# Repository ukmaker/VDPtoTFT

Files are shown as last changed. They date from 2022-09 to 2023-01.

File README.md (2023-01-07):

# VDPtoTFT
Converts the output from an old TMS9928A Video Display Processor to drive a small TFT panel using either an SPI or a parallel interface. For lovers of microcomputers from the 70s and 80s.

# Introduction
Once upon a time, when I were a lad, I had my very own Z80 based computer (Nascom 2) which I had built from a kit and then extended with cards of my own design. I always wanted a colour graphics card, and was most envious of computers which used the Texas Instruments TMS9918 family of chips. I never did get a graphics card, though I did build a two-channel DtoA converter and used that to drive my oscilloscope.

So, wind forward to todayish and I'm in the middle of a project to build a drum machine, when I discover a simple computer I'd cobbled together on a breadboard and which was now living in a box in the shed. Putting two and two together, I decided to see whether it would have been possible to build the drum machine using 70s technology. First thing to do was to decide on what would take the place of the TFT display. You can see where this is going, and how very deep that rabbit-hole is.

Right.

So, for anyone with an old computer using one of the TMS9928/29/128/129 chips, here is a project which will allow you to use it to drive a small, cheap TFT display. It won't work with the TMS9918 chips because it needs to sample the Y and R-Y outputs which don't exist on the TMS9918.

All it needs is an STM32G4 microcontroller. I used a Nucleo-G474RE board because I had one already.

# But Does It Work?
Yes, it does. I confess to being suprised that I was able to make it work. There is a little bit of flicker in a couple of the colours, due to noise in the sampling process, so I have a couple of improvements I'll be working on. 
- Tweak the on-board VREF to output a lower voltage (2.8V instead of 3.25) thus potentially increasing the ADC accuracy.
- Build a better custom PCB. The first version has some errors.

I may end up making a custom PCB including the TMS chip so there's an all-in-one solution for RC2014 folks. Let me know if you would like this.

# Pictures

My VDP board with the Nucleo bolted to the side
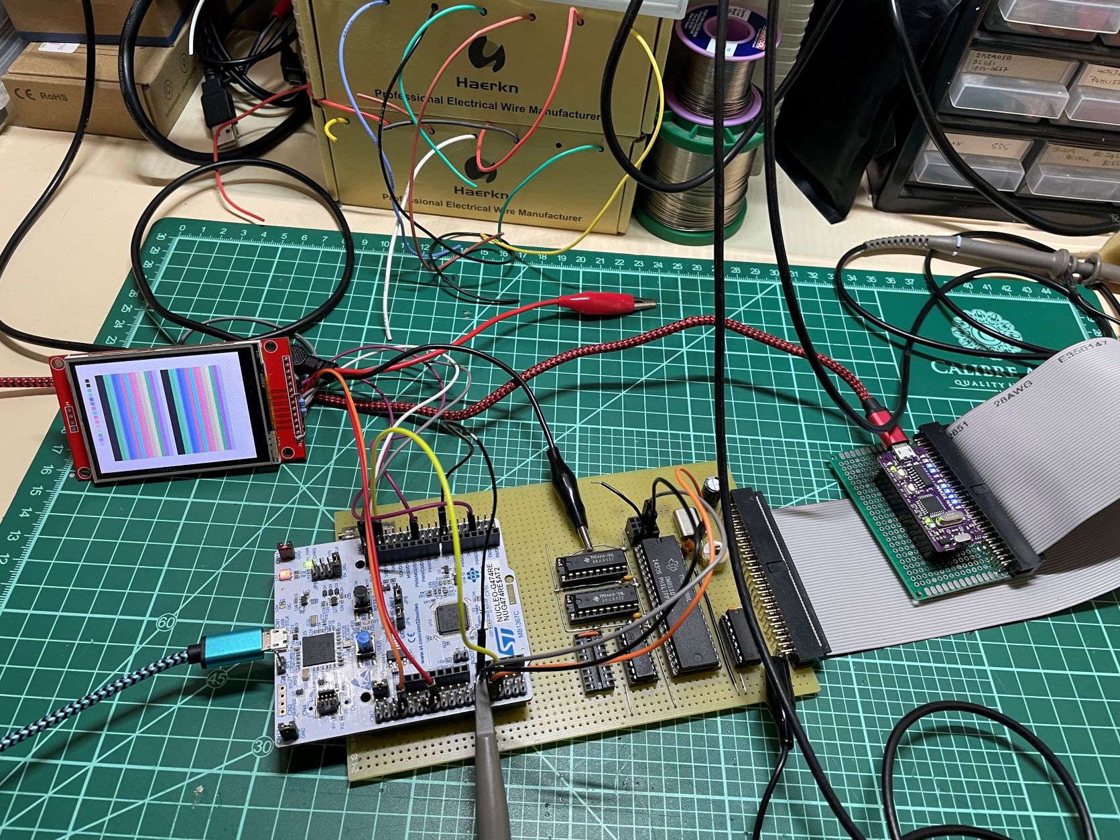
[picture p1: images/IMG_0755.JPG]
VDP Board


Yes, I'm cheating. Driving the VDP from an Arduino for now
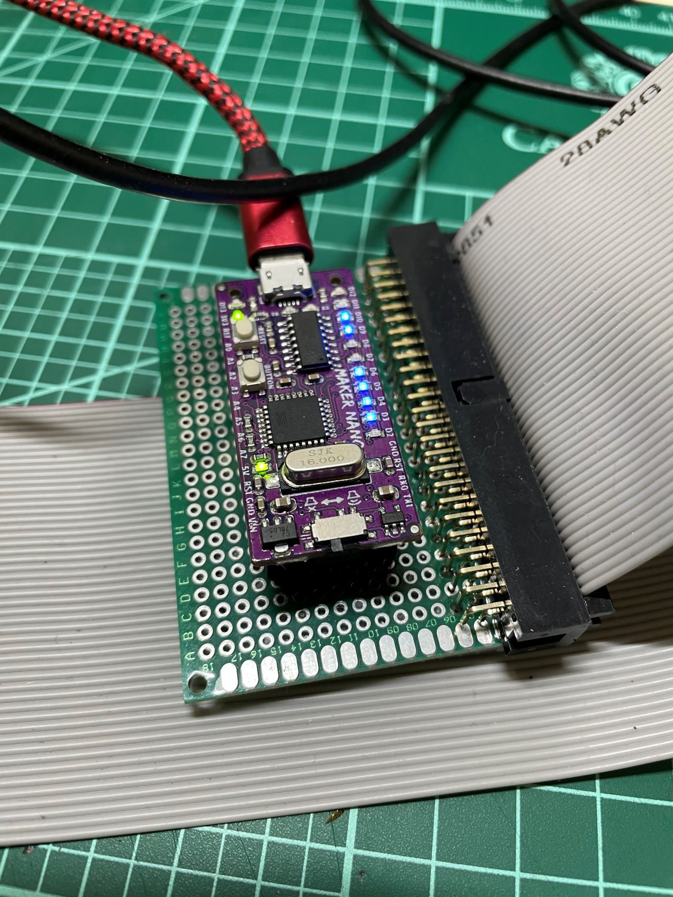
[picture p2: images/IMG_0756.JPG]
Arduino Driving VDP


Close up of an image on the SPI display
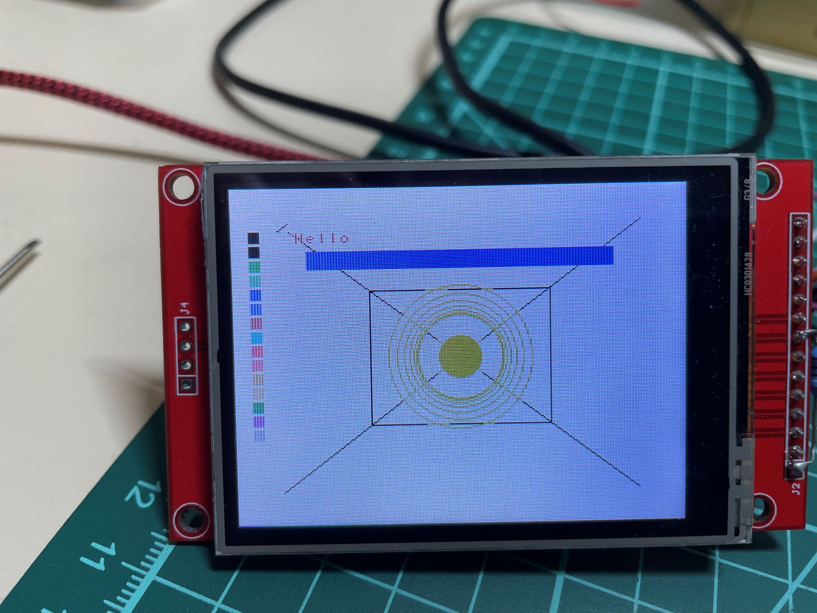
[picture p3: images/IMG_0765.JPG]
SPI Display


And a test-pattern on the parallel display
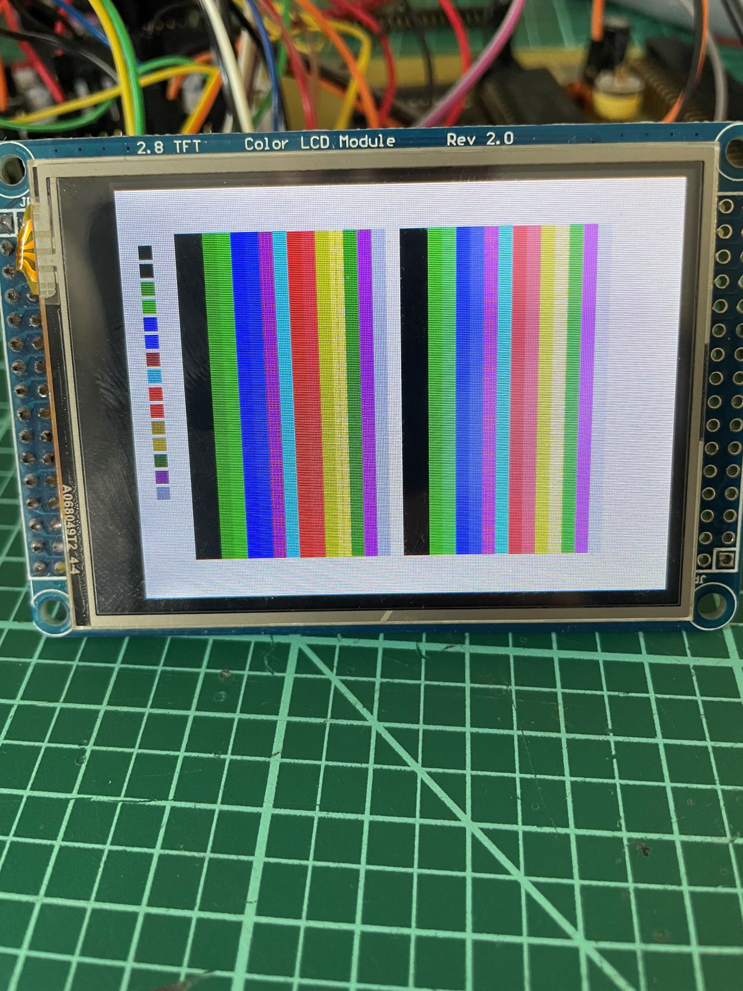
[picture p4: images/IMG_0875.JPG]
Parallel Display


Here's a bit of test-gear I built to help. 
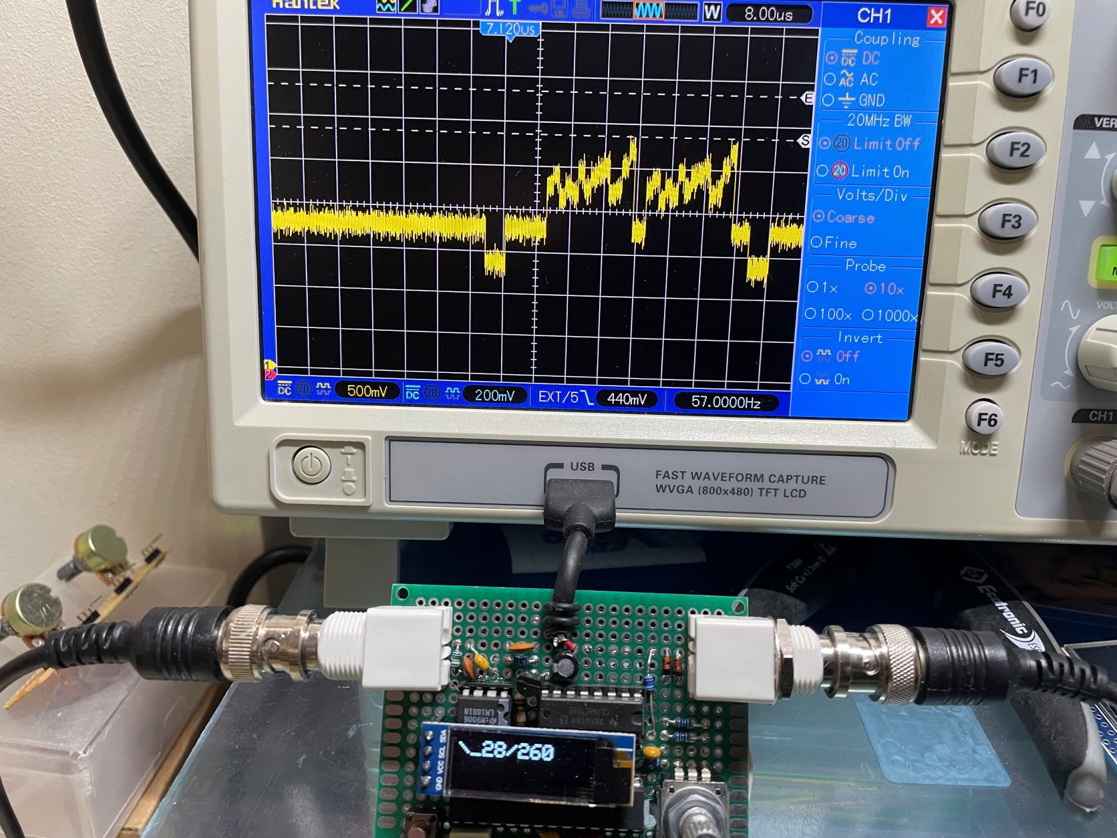
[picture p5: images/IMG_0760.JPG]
VideoTrigger
 - see my other project [VideoTrigger](https://github.com/ukmaker/VideoTrigger) for details

# Theory Of Operation

The following block diagram shows the essentials of how this works.

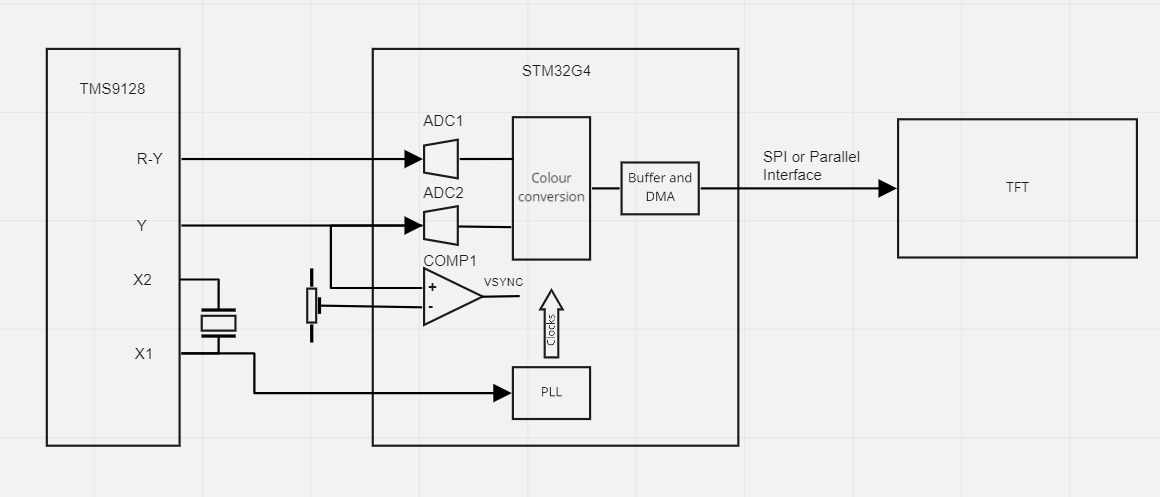
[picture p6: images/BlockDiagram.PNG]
Block Diagram


The output of the VDP's crystal oscillator is used to drive the clock input on the STM32G4. The STM32G4's PLL multiplies the VDP's 10.7MHz clock up by a factor of 16 to 171.2 MHz (thus ever so slightly overclocking the STM32, which is rated to 170MHz). This ensures that all processing happens synchronously to the signals being generated by the VDP. 

The VDP is capable of producing 16 different colours, and the generated signal comes from three outputs - Y, R-Y and B-Y. It turns out that sampling only Y and R-Y give us enough information to deduce the colour being generated, which is good as it reduces the amount of processing needed. These signals are fed to the STM's ADC1 and ADC2 which are operated in "dual-mode". This means that both inputs are sampled synchronously under the control of ADC1. The samples are place in a small circular buffer using DMA.

The ADCs are triggered by a timer which is in turn triggered by a comparator which samples the Y signal to determine when horizontal and vertical sync events happen (when the Y signal level drops below the black value). A trimpot is used to set this level correctly. Once a sync event is detected a chain of two timers is used to generate the sampling signals for the ADCs. The first timer (TIM4) starts the second timer (TIM1) after a delay calculated such that TIM1's first output pulse will happen just as the first pixel data is output by the VDP. This delay is approx 12 microseconds from the horizontal sync pulse.

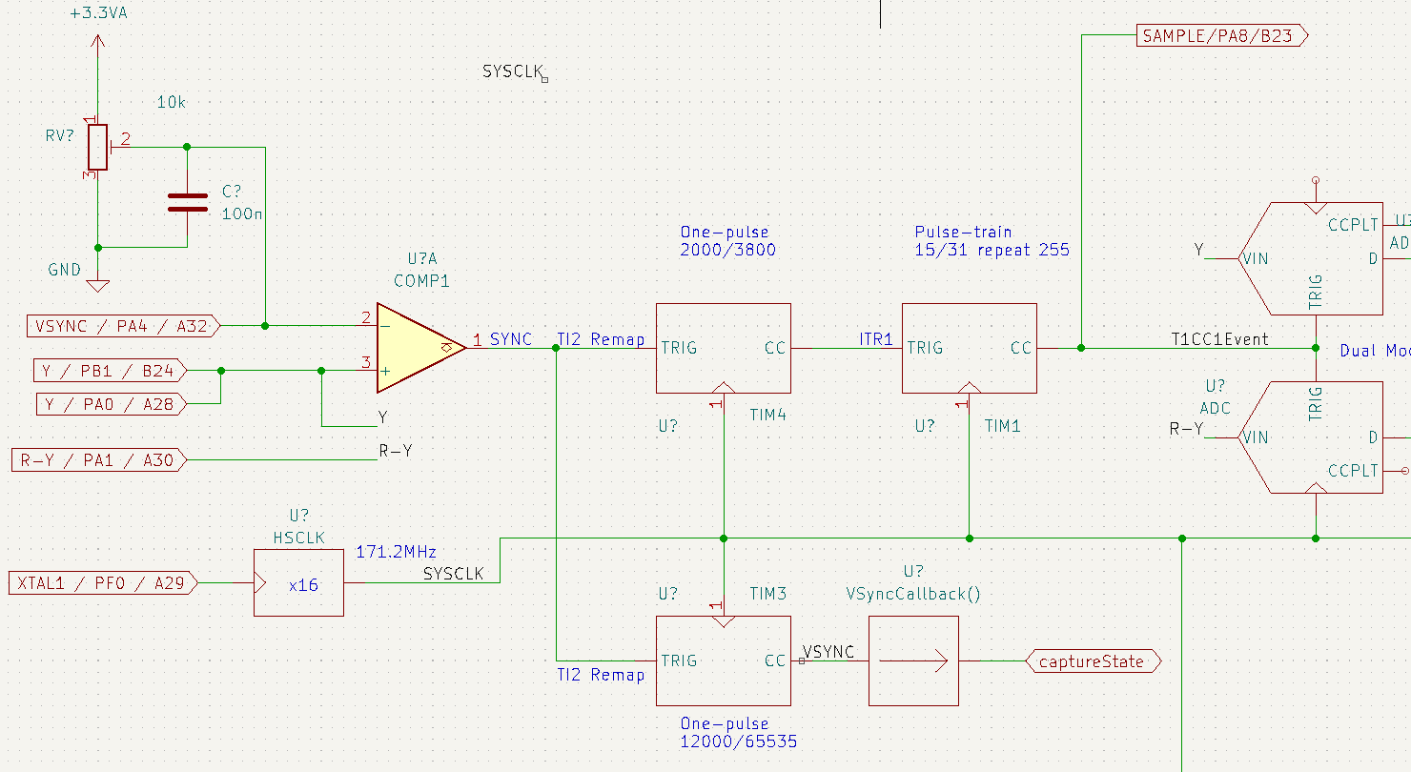
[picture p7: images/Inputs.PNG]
ADC Configuration

The ADC's DMA channel is set to run in circular mode, with a buffer size of 512 half-words. The DMA unit will raise a transfer-half-complete interrupt after 256 transfers, which corresponds to one complete line of pixels. There are now approx 16us available for processing before the start of the next line. The interrupt service routine (ADCCallback()) uses this time to read the data from the buffer, map it from read values (samples are 6 bits per channel) to 16-bit RGB values and store them in the dma buffer, which holds an entire frame of samples. This repeats on the transfer-complete interrupt and so on until and entire frame has been sampled and mapped. 

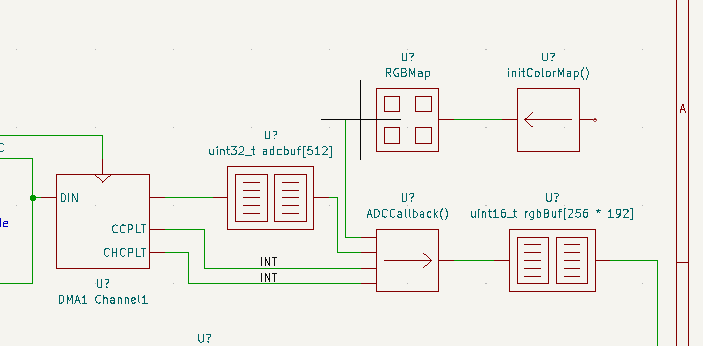
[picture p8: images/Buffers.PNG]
Buffers

If the sync signal stays low for more than one line-time (64 us), TIM3 will detect this as a vertical sync, and raise an interrupt. This is used by the state-machine running in the main() loop to initiate the DMA transfer from the RGB buffer to either the SPI unit or GPIO Port C if a parallel TFT is being used.

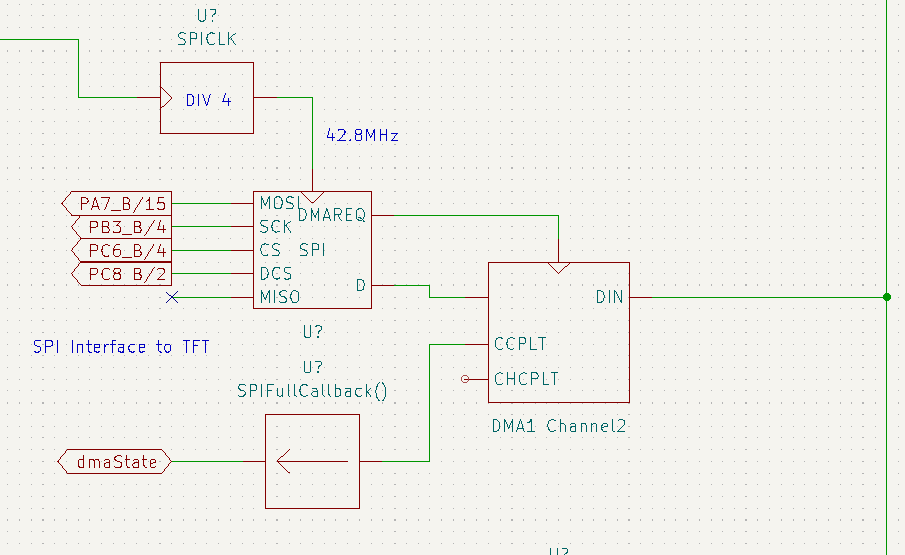
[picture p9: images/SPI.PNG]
SPI

If SPI is being used, the transfer happens in 4 blocks because the maximum size for a single DMA transfer is 65536 transfers. One full frame holds 256 pixels * 192 lines * 2 bytes of data = 98,304 transfers (SPI config for my screen is in bytes). I.e. too many transfers for a single DMA session. The SPI interface is clocked at 42.8MHz, even though the datasheet for the chip used in my display (ILI9341) says the maximum SPI clock speed is 10MHz! Even so, there just is not enough time in one frame to sample and transfer all the data so instead the state machine runs a sample for a frame and then takes a frame to refresh the screen. This is visible as 30Hz flicker on the screen. I have ordered a TMS9129 to use in place of the TMS9128. The TMS9129 is the European version which has a 50Hz refresh rate rather than the 60Hz of the TMS9128. With this lower frame rate I think I'll be able to refresh the screen over SPI at a full 50Hz, thus eliminating the flicker.

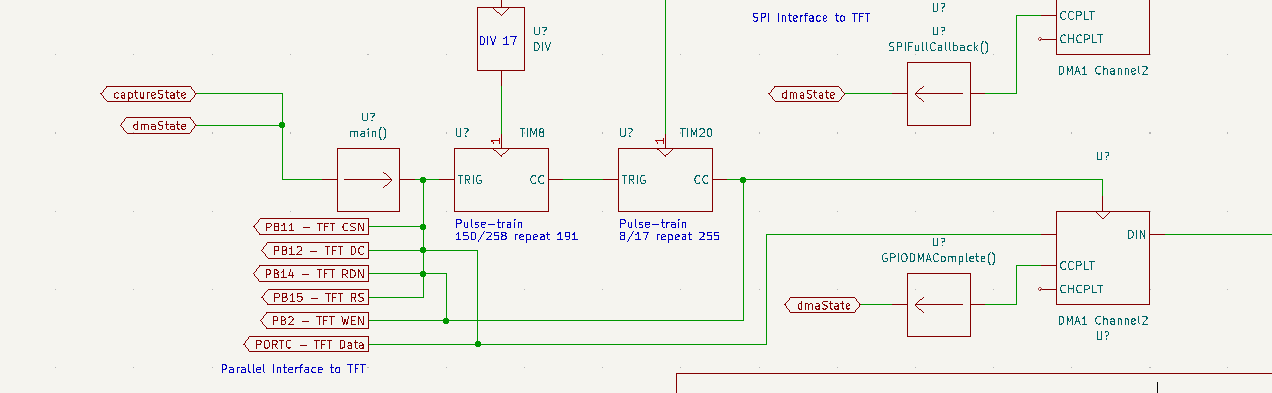
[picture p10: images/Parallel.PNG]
Parallel

If a parallel interface is being used the DMA controller can transfer the entire 49K RGB buffer in one go at 60Hz, so there is no flicker. The parallel interface runs at 10MHz.

# Building
This is a project built using the STM32CubeIDE and the STM32 HAL. If this offends you, feel free to fork my repo and rewrite it in whatever manner you choose.

For now, there is little to do to build this other than

- Install STM32CubeIDE if you haven't already got it
- Download this repo
- Open the project in the IDE and build it
- Tweak appropriate jumpers on your Nucleo (see below)
- Wire up a trimpot to set the sync level
- Connect the Nucleo to the display of your choice (see below)
- Connect the Nucleo to your VDP
- Plug everything in 
- Click Run in the IDE

Note that all the code etc is in the V1.0 directory. I had some small learning opportunities once I'd received my first set of PCBs, and the changes in the V2.0 folder are just for the schematic and layout.

The ConverterBoard directory contains a schematic for implementing this directly with an STM32G474.

The VDPtoSPI directory contains pseudo-schematics for how the blocks in the MCU are used.

## Nucleo Tweaking
Because I needed to use quite a few pins in non-standard ways (for a Nucleo), I needed to remove quite a few jumpers. I'm not sure I remember them all now, but here goes:

### Using the clock from the VDP to drive HSE on PF0.
```
SB28 ON (Connect OSCIN to PF0 header pin)
SB24, SB25, SB26, 27 OFF 
```
### Connect PC14 and PC15 to header pins
```
SB29, SB32 ON
```

### The Sync Trimpot
The sync signal is derived by configuring Comparator 1 and feeding the positive input with the Y signal and the negative input with a constant voltage from a trimpot to set the threshold. Connecct a trimmer of e.g. 10K to 3V3 and GND, with the wiper going to PB1. You should also add a decoupling capacitor of e.g. 100n from PB1 to ground.

Once the board is up and running and you are feeding it a signal from your VDP, adjust the trimpot to obtain a stable display. This can bbe made easier with a two-channel scope attached to Y and PB1 so you can position the voltage on PB1 in the middle of the sync tips.

If you have trouble getting your scope to sync to the VDP signal you might want to look at my other project which is a tool to get a clean trigger off any chosen line on the display. https://github.com/ukmaker/VideoTrigger

## Connecting Your Display
The code is capable of driving displays using either an SPI or parallel interface. 

Configuration is in the file

`V1.0/STM32CubeIDE/VDPDMA/Core/Inc/configuration.h`

By default the code expects to use an SPI interface using SPI2
```
  CS - PB9
  DC - PB8
  RS - PD2
  MOSI - PA11
  SCK - PF1
```
If you uncomment the line
`#define PAR_TFT`
then the code will expect a parallel display
```
D0 - D15 -> PC0 - PC15
CS - PB11
RS - PB12
RD - PB14
RESET - PB15
```

# Making the PCB
Don't use the V1.0 board - there are some annoying errors.

Also, I hope you're better at soldering surface-mount than I am. My first attempt is best described using words like "embarrassment", "cringe" and "pillock". Watch out for those STM chips. Sometimes they have two little circles on the package. Make sure you know which one means Pin 1 Is Here. Then make sure again.

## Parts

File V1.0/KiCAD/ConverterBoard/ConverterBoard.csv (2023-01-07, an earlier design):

Source: | Z:\duncan\EDA\VDPtoTFT\V1.0\KiCAD\ConverterBoard\ConverterBoard.kicad_sch
Date: | 05/11/2022 14:20:18
Tool: | Eeschema (6.0.6)
Generator: | C:\Program Files\KiCad\6.0\bin\scripting\plugins/bom_csv_grouped_by_value_with_fp.py
Component Count: | 48
Ref | Qnty | Value | Cmp name | Footprint | Description | Vendor
C1, C4, C5, C6, C7, C8, C9, C11, C12, C13, C14, C16, C17, | 13 | 100n | C | Capacitor_SMD:C_0805_2012Metric | Unpolarized capacitor
C2, C3, | 2 | 22p | C | Capacitor_SMD:C_0805_2012Metric | Unpolarized capacitor
C10, | 1 | 1u | C | Capacitor_SMD:C_0805_2012Metric | Unpolarized capacitor
C15, C18, C19, | 3 | 4u7 | C | Capacitor_SMD:C_0805_2012Metric | Unpolarized capacitor
D1, | 1 | ESDA6V1-5SC6 | ESDA6V1-5SC6 | Package_TO_SOT_SMD:SOT-23-6 | Quintuple bidirectional transil, Suppressor for ESD protection, 6V1 Breakdown, SOT-23-6
ENCODER1, | 1 | ENCODER | Conn_01x05 | Connector_PinHeader_2.54mm:PinHeader_1x05_P2.54mm_Vertical | Generic connector, single row, 01x05, script generated (kicad-library-utils/schlib/autogen/connector/)
J1, | 1 | 5V Power | Conn_01x02 | TerminalBlock:TerminalBlock_bornier-2_P5.08mm | Generic connector, single row, 01x02, script generated (kicad-library-utils/schlib/autogen/connector/)
J2, J3, J5, | 3 | Conn_01x02 | Conn_01x02 | Connector_PinHeader_2.54mm:PinHeader_1x02_P2.54mm_Vertical | Generic connector, single row, 01x02, script generated (kicad-library-utils/schlib/autogen/connector/)
J6, | 1 | TFT Parallel Port | Conn_02x16_Odd_Even | Connector_PinHeader_2.54mm:PinHeader_2x16_P2.54mm_Vertical | Generic connector, double row, 02x16, odd/even pin numbering scheme (row 1 odd numbers, row 2 even numbers), script generated (kicad-library-utils/schlib/autogen/connector/)
J7, | 1 | GPIO | Conn_02x04_Odd_Even | Connector_PinHeader_2.54mm:PinHeader_2x04_P2.54mm_Vertical | Generic connector, double row, 02x04, odd/even pin numbering scheme (row 1 odd numbers, row 2 even numbers), script generated (kicad-library-utils/schlib/autogen/connector/)
J8, | 1 | TFT SPI Port | Conn_02x04_Odd_Even | Connector_PinHeader_2.54mm:PinHeader_2x04_P2.54mm_Vertical | Generic connector, double row, 02x04, odd/even pin numbering scheme (row 1 odd numbers, row 2 even numbers), script generated (kicad-library-utils/schlib/autogen/connector/)
L1, | 1 | 600R @ 100MHz | L | Inductor_SMD:L_0805_2012Metric_Pad1.15x1.40mm_HandSolder | Inductor
R1, R2, R3, R4, R6, | 5 | 47R | R | Resistor_SMD:R_0805_2012Metric_Pad1.20x1.40mm_HandSolder | Resistor
R5, | 1 | 10R | R | Resistor_SMD:R_0805_2012Metric_Pad1.20x1.40mm_HandSolder | Resistor
R7, | 1 | 3K9 | R | Resistor_SMD:R_0805_2012Metric_Pad1.20x1.40mm_HandSolder | Resistor
RV1, | 1 | 10K | R_Potentiometer_Trim | Potentiometer_THT:Potentiometer_Bourns_3005_Horizontal | Trim-potentiometer
ST-LINK1, | 1 | ST-LINK | Conn_02x05_Odd_Even | Connector_PinHeader_2.54mm:PinHeader_2x05_P2.54mm_Vertical | Generic connector, double row, 02x05, odd/even pin numbering scheme (row 1 odd numbers, row 2 even numbers), script generated (kicad-library-utils/schlib/autogen/connector/)
TP1, TP2, TP3, TP4, TP5, TP6, TP7, | 7 | TestPoint | TestPoint | TestPoint:TestPoint_THTPad_1.5x1.5mm_Drill0.7mm | test point
U1, U2, | 2 | XC6503D331PR-G | XC6503D331PR-G | Package_TO_SOT_SMD:SOT-89-5_Handsoldering
U3, | 1 | MCU_STM32G474RCT6 | MCU_STM32G474RE | Package_QFP:LQFP-64_10x10mm_P0.5mm

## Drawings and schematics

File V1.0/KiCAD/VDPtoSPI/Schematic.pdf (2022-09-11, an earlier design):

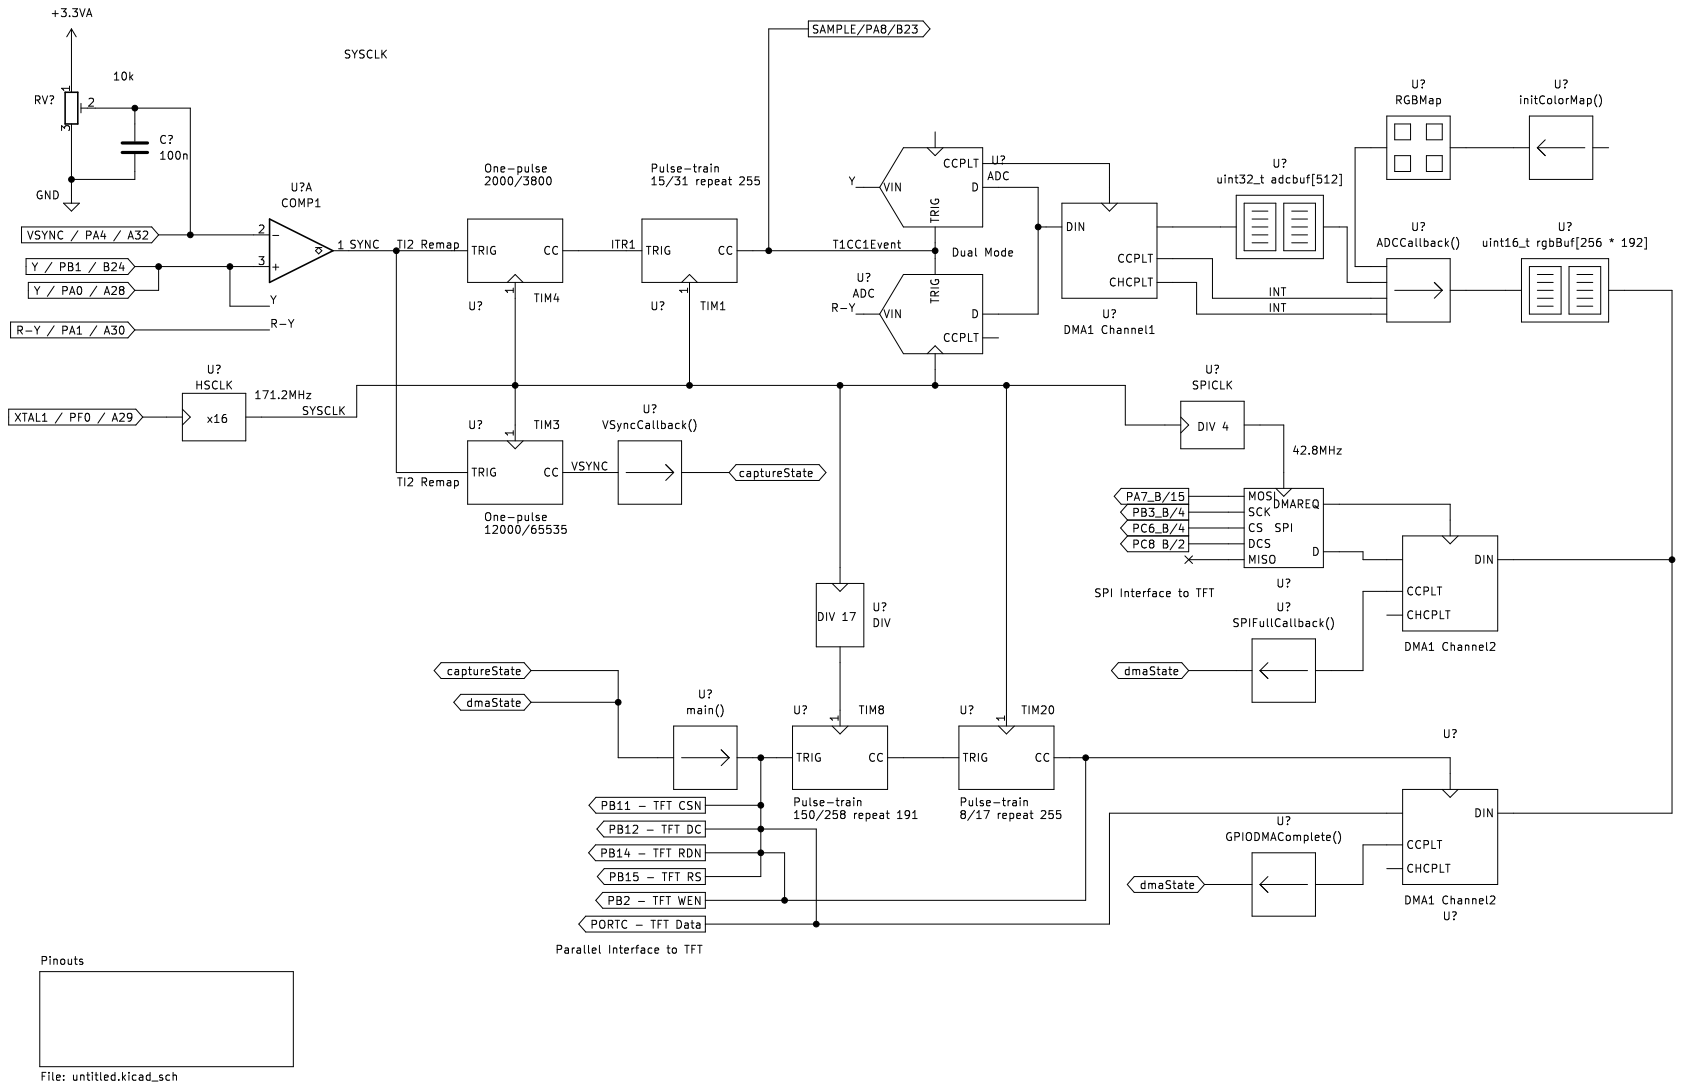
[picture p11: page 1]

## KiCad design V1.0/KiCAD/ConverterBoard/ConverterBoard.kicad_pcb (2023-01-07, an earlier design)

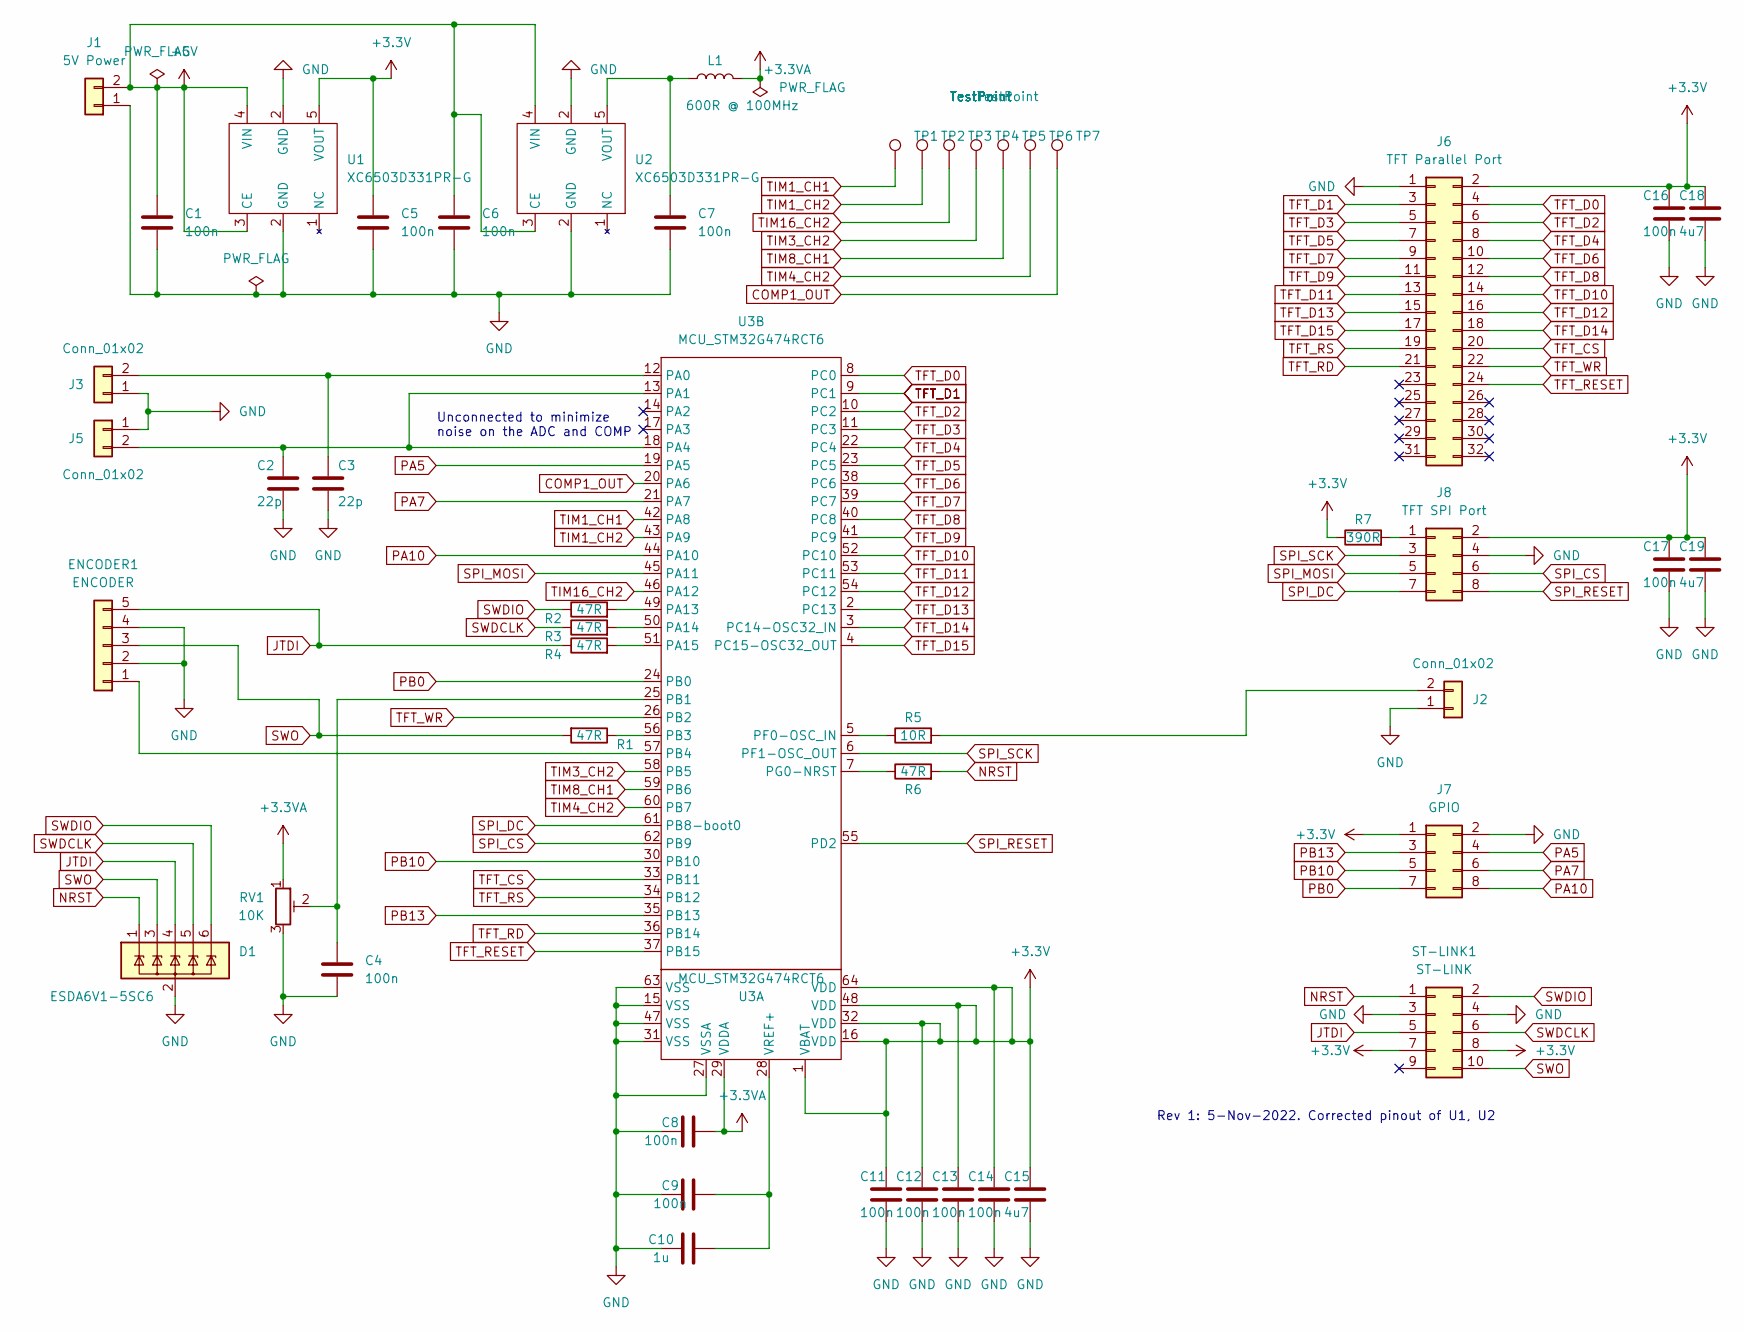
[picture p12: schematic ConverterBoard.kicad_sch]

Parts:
C1, C4, C5, C6, C7, C8, C9, C11, C12, C13, C14, C16, C17: 100n; C_0805_2012Metric
C2, C3: 22p; C_0805_2012Metric
C10: 1u; C_0805_2012Metric
C15, C18, C19: 4u7; C_0805_2012Metric
D1: ESDA6V1-5SC6; SOT-23-6
ENCODER1: ENCODER; PinHeader_1x05_P2.54mm_Vertical
J1: 5V Power; TerminalBlock_bornier-2_P5.08mm
J2, J3, J5: Conn_01x02; PinHeader_1x02_P2.54mm_Vertical
J6: TFT Parallel Port; PinHeader_2x16_P2.54mm_Vertical
J7: GPIO; PinHeader_2x04_P2.54mm_Vertical
J8: TFT SPI Port; PinHeader_2x04_P2.54mm_Vertical
L1: 600R @ 100MHz; L_0805_2012Metric_Pad1.15x1.40mm_HandSolder
R1, R2, R3, R4, R6: 47R; R_0805_2012Metric_Pad1.20x1.40mm_HandSolder
R5: 10R; R_0805_2012Metric_Pad1.20x1.40mm_HandSolder
R7: 390R; R_0805_2012Metric_Pad1.20x1.40mm_HandSolder
RV1: 10K; Potentiometer_Bourns_3005_Horizontal
ST-LINK1: ST-LINK; PinHeader_2x05_P2.54mm_Vertical
TP1, TP2, TP3, TP4, TP5, TP6, TP7: TestPoint; TestPoint_THTPad_1.5x1.5mm_Drill0.7mm
U1, U2: XC6503D331PR-G; SOT-89-5_Handsoldering
U3: MCU_STM32G474RCT6; LQFP-64_10x10mm_P0.5mm

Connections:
+3.3V: C5.1, C11.1, C12.1, C13.1, C14.1, C15.1, C16.1, C17.1, C18.1, C19.1, J6.2, J7.1, J8.2, R7.1, ST-LINK1.7, ST-LINK1.8, U1.5 (VOUT), U3.1 (VBAT), U3.16 (VDD), U3.32 (VDD), U3.48 (VDD), U3.64 (VDD)
+3.3VA: C8.2, L1.2, RV1.1, U3.29 (VDDA)
+5V: C1.1, C6.1, J1.2, U1.3 (CE), U1.4 (VIN), U2.3 (CE), U2.4 (VIN)
COMP1_OUT: TP7.1, U3.20 (PA6)
GND: C1.2, C2.2, C3.2, C4.2, C5.2, C6.2, C7.2, C8.1, C9.1, C10.1, C11.2, C12.2, C13.2, C14.2, C15.2, C16.2, C17.2, C18.2, C19.2, D1.2 (GND), ENCODER1.2, ENCODER1.4, J1.1, J2.1, J3.1, J5.1, J6.1, J7.2, J8.4, RV1.3, ST-LINK1.3, ST-LINK1.4, U1.2 (GND), U2.2 (GND), U3.15 (VSS), U3.27 (VSSA), U3.31 (VSS), U3.47 (VSS), U3.63 (VSS)
JTDI: D1.4 (IO3), ENCODER1.5, R4.1, ST-LINK1.5
NRST: D1.1 (IO1), R6.2, ST-LINK1.1
unnamed: C2.1, J5.2, U3.13 (PA1), U3.18 (PA4)
unnamed: C3.1, J3.2, U3.12 (PA0)
unnamed: C4.1, RV1.2, U3.25 (PB1)
unnamed: C9.2, C10.2, U3.28 (VREF+)
unnamed: ENCODER1.1, U3.57 (PB4)
unnamed: J2.2, R5.2
unnamed: J8.1, R7.2
unnamed: R1.1, U3.56 (PB3)
unnamed: R2.2, U3.49 (PA13)
unnamed: R3.2, U3.50 (PA14)
unnamed: R4.2, U3.51 (PA15)
unnamed: R5.1, U3.5 (PF0-OSC_IN)
unnamed: R6.1, U3.7 (PG0-NRST)
unnamed: C7.1, L1.1, U2.5 (VOUT)
PA5: J7.4, U3.19 (PA5)
PA7: J7.6, U3.21 (PA7)
PA10: J7.8, U3.44 (PA10)
PB0: J7.7, U3.24 (PB0)
PB10: J7.5, U3.30 (PB10)
PB13: J7.3, U3.35 (PB13)
SPI_CS: J8.6, U3.62 (PB9)
SPI_DC: J8.7, U3.61 (PB8-boot0)
SPI_MOSI: J8.5, U3.45 (PA11)
SPI_RESET: J8.8, U3.55 (PD2)
SPI_SCK: J8.3, U3.6 (PF1-OSC_OUT)
SWDCLK: D1.5 (IO4), R3.1, ST-LINK1.6
SWDIO: D1.6 (IO5), R2.1, ST-LINK1.2
SWO: D1.3 (IO2), ENCODER1.3, R1.2, ST-LINK1.10
TFT_CS: J6.20, U3.33 (PB11)
TFT_D0: J6.4, U3.8 (PC0)
TFT_D1: J6.3, U3.9 (PC1)
TFT_D2: J6.6, U3.10 (PC2)
TFT_D3: J6.5, U3.11 (PC3)
TFT_D4: J6.8, U3.22 (PC4)
TFT_D5: J6.7, U3.23 (PC5)
TFT_D6: J6.10, U3.38 (PC6)
TFT_D7: J6.9, U3.39 (PC7)
TFT_D8: J6.12, U3.40 (PC8)
TFT_D9: J6.11, U3.41 (PC9)
TFT_D10: J6.14, U3.52 (PC10)
TFT_D11: J6.13, U3.53 (PC11)
TFT_D12: J6.16, U3.54 (PC12)
TFT_D13: J6.15, U3.2 (PC13)
TFT_D14: J6.18, U3.3 (PC14-OSC32_IN)
TFT_D15: J6.17, U3.4 (PC15-OSC32_OUT)
TFT_RD: J6.21, U3.36 (PB14)
TFT_RESET: J6.24, U3.37 (PB15)
TFT_RS: J6.19, U3.34 (PB12)
TFT_WR: J6.22, U3.26 (PB2)
TIM1_CH1: TP1.1, U3.42 (PA8)
TIM1_CH2: TP2.1, U3.43 (PA9)
TIM3_CH2: TP4.1, U3.58 (PB5)
TIM4_CH2: TP6.1, U3.60 (PB7)
TIM8_CH1: TP5.1, U3.59 (PB6)
TIM16_CH2: TP3.1, U3.46 (PA12)

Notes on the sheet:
Rev 1: 5-Nov-2022. Corrected pinout of U1, U2
Unconnected to minimize noise on the ADC and COMP

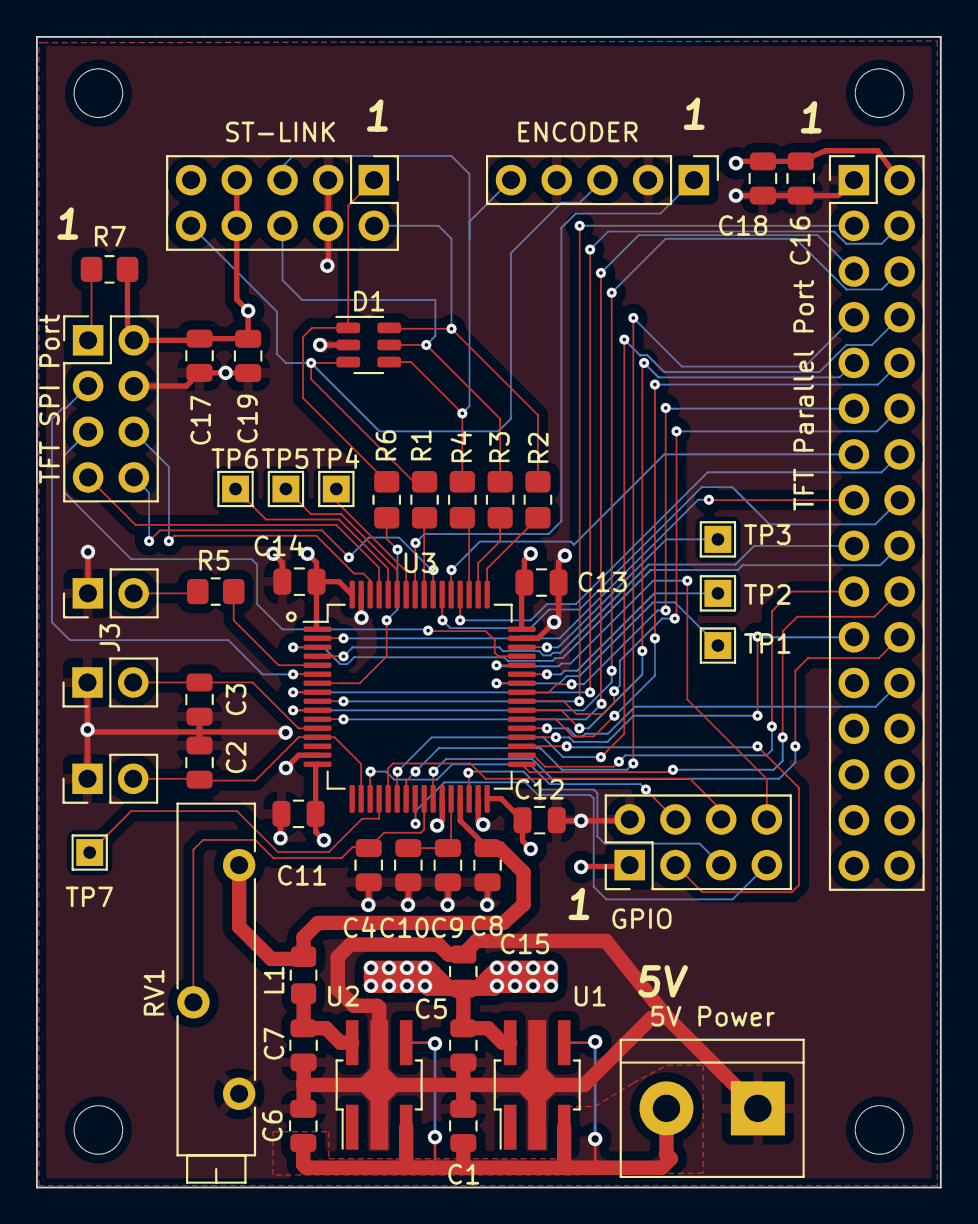
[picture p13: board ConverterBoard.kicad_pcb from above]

Board: 4 copper layers, 50.2 x 63.9 mm, 48 parts (0 on the bottom side), 62 nets.

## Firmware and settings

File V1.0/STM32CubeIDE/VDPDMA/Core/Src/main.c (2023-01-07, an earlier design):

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
/* Includes ------------------------------------------------------------------*/
#include "main.h"
#include "adc.h"
#include "comp.h"
#include "dma.h"
#include "spi.h"
#include "tim.h"
#include "gpio.h"

/* USER CODE BEGIN Includes */
#include "vdp.h"
#include "math.h"
/* USER CODE END Includes */

/* USER CODE BEGIN PD */

#define BLANKING_LINES (28 + (260 - 249))
#define FRAME_LINES 261

#define FIRST_VISIBLE_LINE 40
#define VISIBLE_LINES 192
#define LAST_VISIBLE_LINE (FIRST_VISIBLE_LINE + VISIBLE_LINES - 1)
#define BOTTOM_BORDER 32

#define PIXELS_PER_LINE 256

#define RGB_BUF_LEN (VISIBLE_LINES * PIXELS_PER_LINE)
#ifdef PAR_TFT
	#define RGB_BUF_CHUNKS 1
#else
	#define RGB_BUF_CHUNKS 4
#endif

#define RGB_BUF_CHUNK_BYTES (RGB_BUF_LEN / RGB_BUF_CHUNKS * 2)

#define CAPTURE_STATE_SEEKING_SYNC 0
#define CAPTURE_STATE_FOUND_SYNC 1
#define CAPTURE_STATE_START_GRAB 2
#define CAPTURE_STATE_GRABBING 3
#define CAPTURE_STATE_GRABBED 4
#define CAPTURE_STATE_IDLE 5

#define DMA_CAPTURE_STATE_IDLE 0
#define DMA_STATE_START 1
#define DMA_STATE_RUNNING 2
#define DMA_STATE_CHUNK_COMPLETE 3

#define SETUP_STATE_IDLE 0
#define SETUP_STATE_INIT 1
#define SETUP_STATE_SELECT_COLOUR 2
#define SETUP_STATE_INIT_Y 3
#define SETUP_STATE_TUNE_Y 4
#define SETUP_STATE_INIT_RY 5
#define SETUP_STATE_TUNE_RY 6
#define SETUP_STATE_TUNE_SAMPLE_TIME 7
#define SETUP_STATE_CANCEL 8

#define BUTTONEVENT_CLICK 1
#define BUTTON_EVENT_LONG_PRESS 2

/* USER CODE END PD */


void SystemClock_Config(void);
/* USER CODE BEGIN PFP */
extern void mysetup();
extern int mymain(uint16_t);
extern void pushpixel(uint16_t);

/* USER CODE END PFP */

/* USER CODE BEGIN 0 */

volatile uint16_t rgbBuf[RGB_BUF_LEN];
volatile uint32_t rgbBufIdx;
uint8_t rgbBufchunk;

volatile uint32_t adcbuf[512];
volatile uint32_t adc3buf[512];
volatile int16_t line;
volatile uint8_t captureState;
volatile uint8_t frameReady;
volatile uint8_t dmaState;

volatile uint16_t pix;

uint8_t encoderChanged;
uint8_t encoderPosition;
uint8_t lastPressed;
uint32_t encoderButtonChangedTicks;
uint8_t setupColour;

uint8_t raisedClickedEvent;
uint8_t raisedLongPressEvent;

uint8_t encoderClickedEvent;
uint8_t encoderLongPressEvent;


uint8_t setupState;

int _write(int file, char *ptr, int len) {
	int DataIdx;
	for (DataIdx = 0; DataIdx < len; DataIdx++) {
		ITM_SendChar(*ptr++);
	}
	return len;
}

/* USER CODE END 0 */

/**
  * @brief  The application entry point.
  * @retval int
  */
int main(void)
{
  /* MCU Configuration--------------------------------------------------------*/

  /* Reset of all peripherals, Initializes the Flash interface and the Systick. */
  HAL_Init();

  /* Configure the system clock */
  SystemClock_Config();

  /* Initialize all configured peripherals */
  MX_GPIO_Init();
  MX_DMA_Init();
  MX_TIM8_Init();
  MX_TIM1_Init();
  MX_ADC1_Init();
  MX_ADC2_Init();
  MX_TIM3_Init();
  MX_TIM2_Init();
  MX_TIM4_Init();
  MX_COMP1_Init();
  MX_TIM5_Init();
  MX_TIM16_Init();
  MX_TIM20_Init();
  MX_SPI2_Init();
  /* USER CODE BEGIN 2 */
	GPIOB->MODER = (GPIOB->MODER & 0xFFFFFFCF) | 0x00000010;
	mysetup();

	initBitMap();
	initColorMaps(0.43/0.47, 1.71);

#ifndef PAR_TFT
	swapRGBBytes();
#endif

	HAL_TIM_RegisterCallback(&htim3, HAL_TIM_OC_DELAY_ELAPSED_CB_ID,
			VSyncCallback);

	HAL_SPI_RegisterCallback(&hspi2, HAL_SPI_TX_COMPLETE_CB_ID,
			SPIFullCallback);
	HAL_DMA_RegisterCallback(&hdma_tim20_ch1, HAL_DMA_XFER_CPLT_CB_ID,
			GPIODMAComplete);

	HAL_ADC_RegisterCallback(&hadc1, HAL_ADC_CONVERSION_COMPLETE_CB_ID,
			ADCCallback);
	HAL_ADC_RegisterCallback(&hadc1, HAL_ADC_CONVERSION_HALF_CB_ID,
			ADCCallback);

	HAL_COMP_Start(&hcomp1);
	HAL_TIM_Base_Start(&htim4); // hysnc
	HAL_TIM_Base_Start(&htim1); // sample clock
	HAL_TIM_Base_Start_IT(&htim3); // vsync

	HAL_TIM_Base_Start(&htim8); // Parallel TFT DMA line clock
	HAL_TIM_Base_Start(&htim20); // Parallel TFT DMA pixel clock

	HAL_TIM_Base_Start(&htim2);

	__HAL_TIM_ENABLE_DMA(&htim20, TIM_DMA_CC1);

	if (HAL_TIM_OnePulse_Start(&htim4, TIM_CHANNEL_1) != HAL_OK) {
		/* Starting Error */
		Error_Handler();
	}
	if (HAL_TIM_OnePulse_Start(&htim1, TIM_CHANNEL_1) != HAL_OK) {
		/* Starting Error */
		Error_Handler();
	}
	if (HAL_TIM_OnePulse_Start_IT(&htim3, TIM_CHANNEL_1) != HAL_OK) {
		/* Starting Error */
		Error_Handler();
	}

	if (HAL_TIM_OnePulse_Start_IT(&htim20, TIM_CHANNEL_1) != HAL_OK) {
		/* Starting Error */
		Error_Handler();
	}
	HAL_TIM_OnePulse_Start(&htim8, TIM_CHANNEL_1);

	HAL_TIM_Encoder_Start(&htim2, TIM_CHANNEL_ALL);

	HAL_ADCEx_MultiModeStart_DMA(&hadc1, adcbuf, 512);

	line = BLANKING_LINES; // Line 0 is when we detect vsync at the end of a frame
	captureState = CAPTURE_STATE_SEEKING_SYNC;
	dmaState = DMA_CAPTURE_STATE_IDLE;
	setupState = SETUP_STATE_IDLE;
	encoderPosition = 0;
	encoderChanged = 0;
	lastPressed = GPIO_PIN_SET;
	encoderButtonChangedTicks = 0;
	encoderClickedEvent = 0;
	encoderLongPressEvent = 0;
	setupColour = 0;

	// set to true otherwise there will be a spurious event raised at startup
	raisedClickedEvent = 1;
	raisedLongPressEvent = 0;

	rgbBufIdx = 0;
	rgbBufchunk = 0;
	pix = 0;
	frameReady = 0;

	GPIOB->MODER = (GPIOB->MODER & 0xFFFFFFCF) | 0x00000010;

  /* USER CODE END 2 */

  /* Infinite loop */
  /* USER CODE BEGIN WHILE */
	while (1) {
    /* USER CODE END WHILE */

    /* USER CODE BEGIN 3 */

		handleEncoderInputs();
		updateSetupState();
		processSetupState();

		switch (captureState) {

		case CAPTURE_STATE_SEEKING_SYNC:
			break;

		case CAPTURE_STATE_FOUND_SYNC:
			captureState = CAPTURE_STATE_START_GRAB;
			break;

		case CAPTURE_STATE_GRABBED:
			captureState = CAPTURE_STATE_IDLE;
			frameReady = 1;
			break;

		case CAPTURE_STATE_IDLE:

			if (frameReady == 0) {
				captureState = CAPTURE_STATE_START_GRAB;
				pix=0;
			}

			break;

		default:
			break;
		}

		switch (dmaState) {

		case DMA_CAPTURE_STATE_IDLE:
			if (frameReady == 1) {
				dmaState = DMA_STATE_START;
			}
			break;

		case DMA_STATE_START:

#ifndef PAR_TFT
			while(SPI2->SR & SPI_SR_BSY) {
				__NOP();
			}
			vsync();
			while(SPI2->SR & SPI_SR_BSY) {
				__NOP();
			}
#else
			vsync();
#endif

			rgbBufchunk = 0;
			rgbBufIdx = 0;
			dmaState = DMA_STATE_RUNNING;
#ifndef PAR_TFT
			HAL_SPI_Transmit_DMA(&hspi2, (uint8_t *)&rgbBuf, RGB_BUF_CHUNK_BYTES);
#else
			TIM20->DIER &= ~ TIM_DIER_CC1DE;
			TIM20->DIER |= TIM_DIER_CC1DE;
			HAL_DMA_Start_IT(&hdma_tim20_ch1, (uint32_t)rgbBuf, (uint32_t)&GPIOC->ODR, RGB_BUF_CHUNK_BYTES/2);

			GPIOB->MODER = (GPIOB->MODER & 0xFFFFFFCF) | 0x00000020;

			__HAL_TIM_ENABLE(&htim8);
#endif
			break;

		case DMA_STATE_RUNNING:
			break;

		case DMA_STATE_CHUNK_COMPLETE:
			rgbBufchunk++;

			if (rgbBufchunk == RGB_BUF_CHUNKS) {
				dmaState = DMA_CAPTURE_STATE_IDLE;
				frameReady = 0;
			} else {
				dmaState = DMA_STATE_RUNNING;
#ifndef PAR_TFT
				HAL_SPI_Transmit_DMA(&hspi2, (uint8_t *)&(rgbBuf[rgbBufchunk * RGB_BUF_LEN / RGB_BUF_CHUNKS]), RGB_BUF_CHUNK_BYTES);
#else
				TIM20->DIER &= ~ TIM_DIER_CC1DE;
				TIM20->DIER |= TIM_DIER_CC1DE;
				HAL_DMA_Start_IT(&hdma_tim20_ch1, (uint32_t)&rgbBuf[rgbBufchunk * (RGB_BUF_LEN / RGB_BUF_CHUNKS)], (uint32_t)&GPIOC->ODR, RGB_BUF_CHUNK_BYTES/2);
				GPIOB->MODER = (GPIOB->MODER & 0xFFFFFFCF) | 0x00000020;
				__HAL_TIM_ENABLE(&htim8);
#endif
				}
			break;

		default:
			break;

		}
	}
  /* USER CODE END 3 */
}

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
/* USER CODE BEGIN 4 */

void ADCCallback(ADC_HandleTypeDef *hadc) {
	register uint8_t y;
	register uint8_t ry;
	register uint16_t bits;
	register uint8_t b;
	register uint16_t pixel = pix;
	register uint16_t i = PIXELS_PER_LINE;
	line++;
	if (line > FRAME_LINES)
		line = 1;

	if (captureState != CAPTURE_STATE_GRABBING)
		return;

	if (line > FIRST_VISIBLE_LINE && line < (LAST_VISIBLE_LINE + 2)) { // don't capture the previous line - it was part of frame blanking

		while (i > 0) {

			y = (((uint16_t*) adcbuf)[pixel] & 0xff) >> (8 - ADC_RESOLUTION_BITS);
			ry = (((uint16_t*) adcbuf)[pixel] >> (16 - ADC_RESOLUTION_BITS));

			bits = YMap[y] & RYMap[ry];

			b = bitMap[bits >> 8];
			if(b == 0) {
				b = bitMap[bits & 0xff];
			} else {
				b+=8;
			}

			if (rgbBufIdx < RGB_BUF_LEN) {

				rgbBuf[rgbBufIdx] = rgbMap[b];
				rgbBufIdx++;
			}
			pixel++;
			i--;
		}
	}

	if (pixel >= 512) {
		pixel = 0;
	}

	pix = pixel;
}

void VSyncCallback(TIM_HandleTypeDef *htim) {

	line = LAST_VISIBLE_LINE + BOTTOM_BORDER;
	pix = 0;

	switch (captureState) {
	case CAPTURE_STATE_SEEKING_SYNC:
		captureState = CAPTURE_STATE_FOUND_SYNC;
		break;

	case CAPTURE_STATE_START_GRAB:
		captureState = CAPTURE_STATE_GRABBING;
		rgbBufIdx = 0;
		HAL_ADCEx_MultiModeStart_DMA(&hadc1, adcbuf, 512);
		break;

	case CAPTURE_STATE_GRABBING:
		HAL_ADCEx_MultiModeStop_DMA(&hadc1);
		captureState = CAPTURE_STATE_GRABBED;

	default:
		break;

	}
}

void SPIFullCallback(SPI_HandleTypeDef *spi) {
	dmaState = DMA_STATE_CHUNK_COMPLETE;
}

void GPIODMAComplete(DMA_HandleTypeDef *dma) {
	dmaState = DMA_STATE_CHUNK_COMPLETE;
	__HAL_TIM_DISABLE(&htim8);
	GPIOB->MODER = (GPIOB->MODER & 0xFFFFFFCF) | 0x00000010;
}

void handleEncoderInputs() {
	encoderLongPressEvent = 0;
	encoderClickedEvent = 0;

	uint8_t pressed = HAL_GPIO_ReadPin(ENCODER_PORT, ENCODER_PIN) == GPIO_PIN_RESET;

	if (((htim2.Instance->CNT & 0xff) >> 1) != encoderPosition) {
		encoderPosition = (htim2.Instance->CNT & 0XFF) >> 1;
		encoderChanged = 1;
	} else {
		encoderChanged = 0;
	}

	if (pressed != lastPressed) {
		lastPressed = pressed;
		encoderButtonChangedTicks = HAL_GetTick();
	}

	uint32_t deltaT = HAL_GetTick() - encoderButtonChangedTicks;

	if (pressed && deltaT > ENCODER_BUTTON_DEBOUNCE) {
		raisedClickedEvent = 0;
	}

	if (!pressed && deltaT > ENCODER_BUTTON_DEBOUNCE) {
		if(raisedClickedEvent == 0) {
			raisedClickedEvent = 1;
			if(!raisedLongPressEvent) {
				// only actually raise the event if it is not following a long click
				encoderClickedEvent = 1;
			}
			raisedLongPressEvent = 0;
		}
	} else if (pressed && deltaT > ENCODER_BUTTON_LONG_PRESS) {
		if(raisedLongPressEvent == 0) {
			raisedLongPressEvent = 1;
			encoderLongPressEvent = 1;
		}
	}
}

void updateSetupState() {

	if (encoderLongPressEvent) {
		if(setupState == SETUP_STATE_IDLE) {
			setupState = SETUP_STATE_TUNE_SAMPLE_TIME;
		} else {
			setupState = SETUP_STATE_CANCEL;
		}
	} else {
		if (encoderClickedEvent) {
			switch (setupState) {
			case SETUP_STATE_IDLE:
				setupState = SETUP_STATE_INIT;
				break;
			case SETUP_STATE_SELECT_COLOUR:
				setupState = SETUP_STATE_INIT_Y;
				break;
			case SETUP_STATE_TUNE_Y:
				setupState = SETUP_STATE_INIT_RY;
				break;
			case SETUP_STATE_TUNE_RY:
				setupState = SETUP_STATE_SELECT_COLOUR;
				break;
			default:
				break;
			}
		}
	}
}

void processSetupState() {

	switch(setupState) {
	case SETUP_STATE_CANCEL:
		cancelSetup();
		setupState = SETUP_STATE_IDLE;
		break;
	case SETUP_STATE_INIT:
		initSetup();
		setupState = SETUP_STATE_SELECT_COLOUR;
		htim2.Instance->CNT = 0;
		encoderPosition = 0;
		setupColour = (encoderPosition % 16);
		initSetupColour(setupColour);
		break;
		// no break
	case SETUP_STATE_SELECT_COLOUR:
		if(encoderChanged) {
			setupColour = (encoderPosition % 16);
			initSetupColour(setupColour);
		}
		break;
	case SETUP_STATE_INIT_Y:
		htim2.Instance->CNT = ADC_RESOLUTION_STEPS / 2;
		setupState = SETUP_STATE_TUNE_Y;
		break;
	case SETUP_STATE_TUNE_Y:
		if(encoderChanged) {
			tuneY(setupColour, encoderPosition % ADC_RESOLUTION_STEPS);
		}
		break;
	case SETUP_STATE_INIT_RY:
		htim2.Instance->CNT = ADC_RESOLUTION_STEPS / 2;
		setupState = SETUP_STATE_TUNE_RY;
		break;
	case SETUP_STATE_TUNE_RY:
		if(encoderChanged) {
			tuneRY(setupColour, encoderPosition % ADC_RESOLUTION_STEPS);
		}
		break;
	case SETUP_STATE_TUNE_SAMPLE_TIME:
		// adjust where the ADC sampling starts
		htim4.Instance->CCR1 = 1148 + (encoderPosition % 16) - 8;
		break;
	default:
		break;
	}
}

void cancelSetup() {
	disableSetupGUI();
}

void initSetup() {
	enableSetupGUI();
}

/* USER CODE END 4 */
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


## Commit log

2022-09-11 Initial import
    [VDPtoSPI.kicad_pcb, VDPtoSPI.kicad_sch, configuration.h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]
2022-09-11 Add images
    [configuration.h]
2022-09-12 Sync RGB_BUF_CHUNKS with no of TIM8 repititions
    [ConverterBoard.kicad_pcb, ConverterBoard.kicad_sch]
2022-09-12 Move SPI to SPI2 to free up TIM2 for reading an encoder
    [configuration.h]
2022-09-14 Started to add support for settings
    [configuration.h]
2023-01-07 README update and PCB outputs
    [ConverterBoard-B_Cu.gbr, ConverterBoard-B_Mask.gbr, ConverterBoard-B_Paste.gbr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]

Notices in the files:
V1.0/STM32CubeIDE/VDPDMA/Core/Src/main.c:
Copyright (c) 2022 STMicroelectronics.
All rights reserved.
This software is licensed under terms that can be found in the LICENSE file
